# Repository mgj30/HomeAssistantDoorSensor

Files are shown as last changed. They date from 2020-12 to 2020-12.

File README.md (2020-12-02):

HomeAssistant Door Sensor : MQTTSimpleDoorSensor

Descripción
===========

Dispositivo Open Source, compatible con Home Assistant.

El dispositivo se basa en el encapsulado ESP8266, concretamente en la placa de
desarrollo WEMOS D1 mini.

Se trata de un dispositivo detector de apertura y cierre de puerta, por MQTT,
compatible con Home Assistant en adelante HA.

El dispositivo implementa el protocolo MQTT con auto Discovery de HA, y
proporciona una interfaz grafica de configuración parecida a TASMOTA.

Funcionamiento
==============

Una vez instalado el Firmware y montado la PCB siguiendo el esquemático, el
funcionamiento del dispositivo es el siguiente.

*Puesta en marcha*

En caso de no estar configurado, el dispositivo iniciará su Wifi como AP con el
SSID “SimpleDoorSensor” y contraseña “SimpleDoorSensor”, proporcionando en la
URL <http://192.168.1.1> , una interfaz de configuración, en la cual nos
encontraremos las siguientes opciones:

WIFI Configuration
------------------

En esta sección dispondremos de un formulario en el que podremos introducir, el
SSID y contraseña de la Red WIFI donde el dispositivo tendrá acceso al servidor
MQTT de nuestro HA.

En el formulario encontraremos los siguientes campos:

**SSID1:** SSID de la Red Wifi principal

**PWD1:** Contraseña de la Red Wifi principal

**SSID2:** SSID de la Red Wifi secundaria

**PWD2:** Contraseña de la Red Wifi secundaria

MQTT Configuration
------------------

En esta sección disponemos de un formulario con los siguientes campos, para
poder configurar un servidor MQTT en el que publicar datos.

En el formulario encontraremos los siguientes campos:

**SERVER:** IP o dominio del servidor MQTT

**PORT:** Puerto MQTT

**USER:** Usuario de autenticación

**PWD:** Contraseña de autenticación

**CLIENTID:** Identificación del cliente MQTT

Device Configuration
--------------------

En esta sección encontraremos un formulario con configuraciones generales del
sistema con los siguientes campos:

**HA_AUTODISCOVER:** Activa o desactiva el modo autodiscover

**DV_LEDS_STATUS:** Activa o desactiva encender los led de la PCB al leer la
batería

**DV_DEEPSLEEPTIME:** Por defecto -1(inhabilita dormir), 0 Duerme hasta abrir
puerta, +0 Despierta cada X segundos y publica estado.

**HA_DEVICENAME:** Nombre del dispositivo en HA

**DV_STATUS_PUBLISH_PERIOD:** Periodo de publicación en el caso de DeepSleeTime
= -1, por defecto 5 segundos

En la carpeta “Schematics” encontrareis el proyecto KiCad de la PCB junto con el
esquemático del circuito.

Por otro lado en la carpeta SRC se encuentra el código fuente del proyecto.

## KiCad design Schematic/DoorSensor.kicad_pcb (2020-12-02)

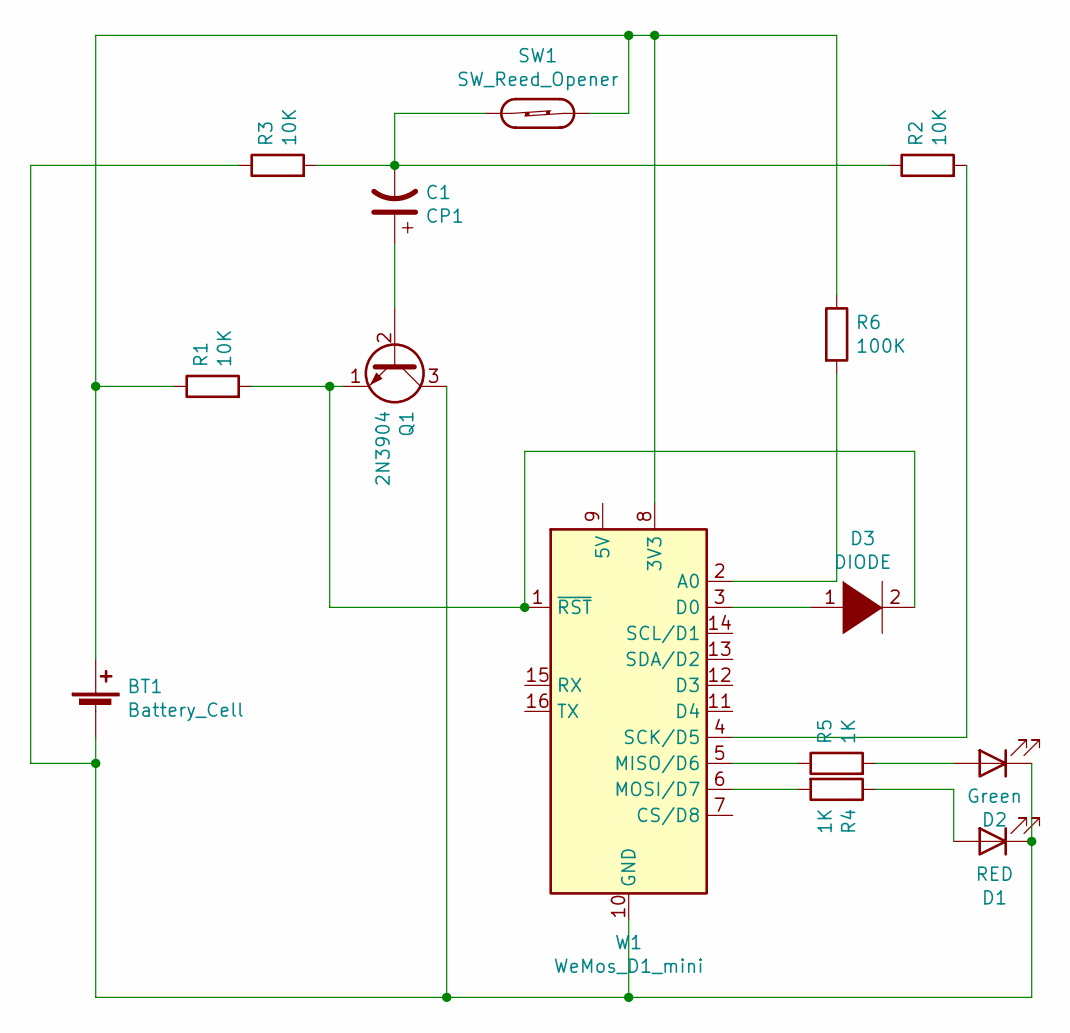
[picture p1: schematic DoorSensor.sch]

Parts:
BT1: Battery_Cell; BatteryHolder_Keystone_1042_1x18650
C1: CP1; CP_Radial_D4.0mm_P1.50mm
D1: RED; LED_D3.0mm
D2: Green; LED_D3.0mm
D3: DIODE; D_A-405_P7.62mm_Horizontal
Q1: 2N3904; TO-92_Inline
R1, R2, R3: 10K; R_Axial_DIN0309_L9.0mm_D3.2mm_P12.70mm_Horizontal
R4, R5: 1K; R_Axial_DIN0309_L9.0mm_D3.2mm_P12.70mm_Horizontal
R6: 100K; R_Axial_DIN0309_L9.0mm_D3.2mm_P12.70mm_Horizontal
SW1: SW_Reed_Opener; THT_reed_switch_20mmL
W1: WeMos_D1_mini; WEMOS_D1_mini_light

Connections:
unnamed: BT1.1 (+), R1.1, R6.1, SW1.2, W1.8 (3V3)
unnamed: BT1.2 (-), D1.1 (K), D2.1 (K), Q1.3 (C), R3.1, W1.10 (GND)
unnamed: C1.1, Q1.2 (B)
unnamed: C1.2, R2.1, R3.2, SW1.1
unnamed: D1.2 (A), R4.1
unnamed: D2.2 (A), R5.2
unnamed: D3.1 (K), W1.3 (D0)
unnamed: D3.2 (A), Q1.1 (E), R1.2, W1.1 (~RST)
unnamed: R2.2, W1.4 (SCK/D5)
unnamed: R4.2, W1.6 (MOSI/D7)
unnamed: R5.1, W1.5 (MISO/D6)
unnamed: R6.2, W1.2 (A0)

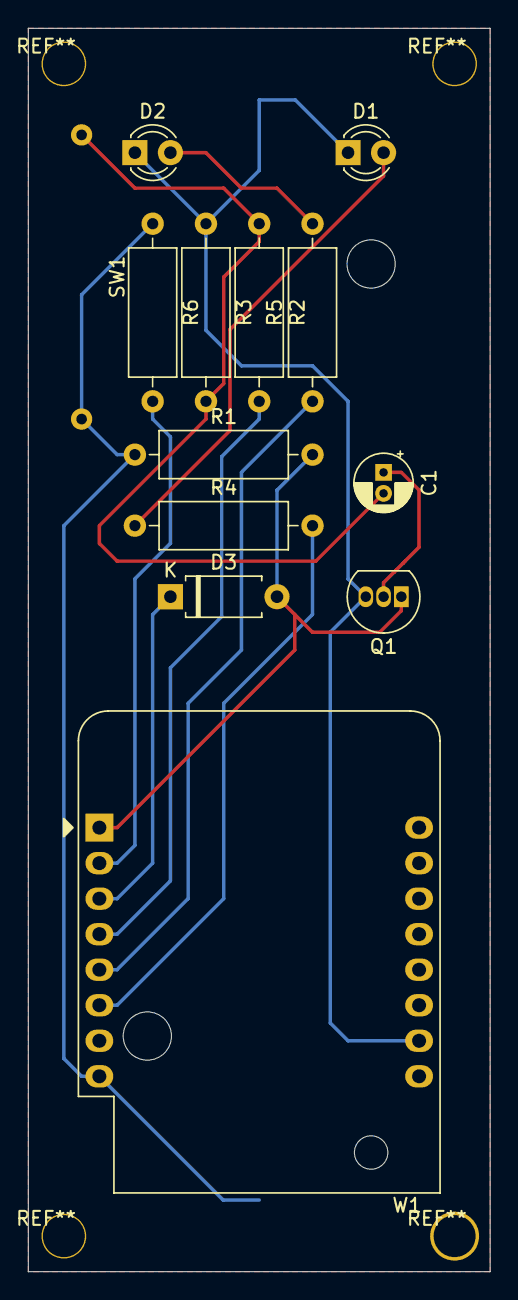
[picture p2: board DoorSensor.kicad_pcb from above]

Board: 2 copper layers, 33.0 x 88.9 mm, 14 parts (1 on the bottom side), 12 nets.

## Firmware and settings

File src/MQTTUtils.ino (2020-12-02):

//Mqtt init
void mqtt_init() 
{ 
  const char* server = mqtt_config["mqtt_server"];
  client.setServer(ser, 1883);//set server info
  client.setCallback(callback);//set callback method
  mqtt_connect();//connect  

  //suscribe topics
  client.subscribe("/alarma/status");//suscribe alarm status
  client.subscribe("/alarma/puerta/get");//suscribe get command for status
  client.subscribe("/alarma/puerta/volt/get");//suscribe get command for volt
  client.subscribe("/alarma/puerta/sleep/get");//suscribe deepsleep cmd
}
//connection function
void mqtt_connect() 
{ 
  while (!client.connected()) //if no connected, reconnect
  {  

    const char* a = mqtt_config["mqtt_clientId"];
    const char* b = mqtt_config["mqttUser"];
    const char* c = mqtt_config["mqttPassword"];
    
    client.connect(a, b,c);//connect 
    delay(250);
  }  
}

void publishMessage(char* topic, char* msg, bool retained){
  //check if wifi connected    
  if((WiFi.status() != WL_CONNECTED))//If no connected, reconnect
  {
    wifi_init();//connect
  }     
     
  if (!client.connected())//If mqtt no conected, reconnect
  {
    mqtt_init();//connect
  }
  Serial.println("");
  Serial.print("Publiss msg to = " );
  Serial.print(topic);
  Serial.println("");
  Serial.print("Msg = " );
  Serial.print(msg);
  client.publish(topic, msg, retained);//send  
}

//call back function mqtt with state machine
void callback(char* topic, byte* payload, unsigned int length)
{
  Serial.println("");
  Serial.print("Receibed msg from = " );
  Serial.print(topic);
   Serial.println("");
  Serial.print("Content = " );
  Serial.print((char*)payload);
  if(strcmp(topic,(char*)ALARM_STATUS_TOPIC)==0)//get alarm status from mqtt
  {
    if (!strncmp((char *)payload, "armed_away", length)) 
    {
      alarmStatus = 1;
      sensorStatus["alarmStatus"]=1;
    } 
    else if (!strncmp((char *)payload, "armed_home", length)) 
    {
      alarmStatus = 2;
      sensorStatus["alarmStatus"]=2;
    }  
    else if (!strncmp((char *)payload, "armed_night", length)) 
    {
      alarmStatus = 3;
      sensorStatus["alarmStatus"]=3;
    }
    else if (!strncmp((char *)payload, "disarmed", length)) 
    {
      alarmStatus = 0;
      sensorStatus["alarmStatus"]=0;
    }  
  }
  
  if(strcmp(topic,CMD_STATUS_GET)==0)//get alarm status from mqtt
  {
    if (!strncmp((char *)payload, "1", length)) //if payload eq 1 response status
    {
      publishMessage(DOOR_STATUS_TOPIC,string2char(sensorStatus.as<String>()), true);
    }      
  }
  
  if(strcmp(topic,CMD_DEEP_SLEEP)==0)//every restart get last retained message
  {  
    int sleepTimeMqtt = atoi((char *)payload);
    sleepTimeS=sleepTimeMqtt;      
    sensorStatus["deepSleepTime"]=sleepTimeMqtt;
    publishMessage(DOOR_STATUS_TOPIC,string2char(sensorStatus.as<String>()), true);
  }
}

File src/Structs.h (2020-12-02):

#define MSG_BUFFER_SIZE  (50) // max message buffer mqtt

#define DEVICE_PREFIX   "Sensor_"

//Pin's Config
#define GREEN_LED   12 //Pin enabled led battery level high status
#define RED_LED     13 //Ping enabled led battery level low status
#define DOOR_STATUS 14 //Pin read door opened or closed

//GENERAL TOPICS
#define ALARM_STATUS_TOPIC     "/alarma/status"
#define DOOR_STATUS_TOPIC      "/alarma/puerta"
#define BATTERY_STATUS_TOPIC   "/alarma/puerta/volt"
#define DEEP_SLEEP_TOPIC       "/alarma/puerta/sleep"

//CMD TOPICS
#define CMD_DEEP_SLEEP         "/alarma/puerta/sleep/get"
#define CMD_BATTERY_STATUS_GET "/alarma/puerta/volt/get"
#define CMD_STATUS_GET         "/alarma/puerta/get"
